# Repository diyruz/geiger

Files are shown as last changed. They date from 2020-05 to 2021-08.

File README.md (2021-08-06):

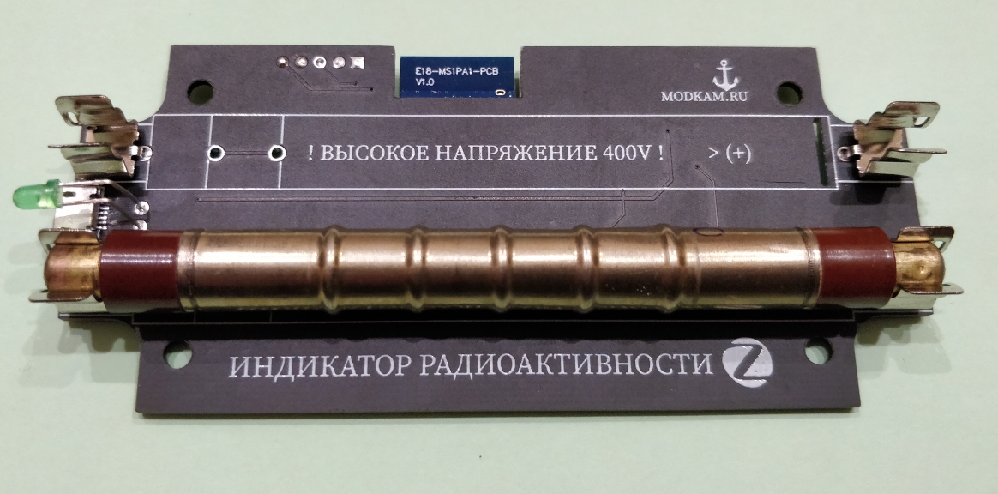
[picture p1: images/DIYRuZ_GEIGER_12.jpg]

We all know what radiation is and its harmful effects on humans. Since this danger is not tangible, in connection with this the idea was born to make an indicator for continuous monitoring of the radiation situation.

The device is not designed to measure the level of radiation in the epicentre of a nuclear explosion, but it allows you to constantly monitor changes in background values. This can be useful in the event of man-made disasters or when you or others bring something with increased background radiation into the house. These can be quite harmless-looking things, nevertheless, they carry a direct threat to life and health.

There are many amateur dosimeter projects, for example, one and two.
All of them are built according to almost the same schemes associated with the features of the Geiger counters used. The principle of operation of Geiger counters is based on the effect of impact ionization of a gaseous medium under the action of radioactive particles in the interelectrode space at a high accelerating voltage. Accordingly, the meter requires a high voltage source.

### How to compile
Follow this article https://zigdevwiki.github.io/Begin/IAR_install/

**ATTENTION! THE DEVICE CONTAINS A HIGH VOLTAGE OF 400 VOLTS**

Since Jager has a Zigbee network at home, the device will be an element of this network.
The circuit does not contain rare elements and is typical for this type of device.

### Diagram
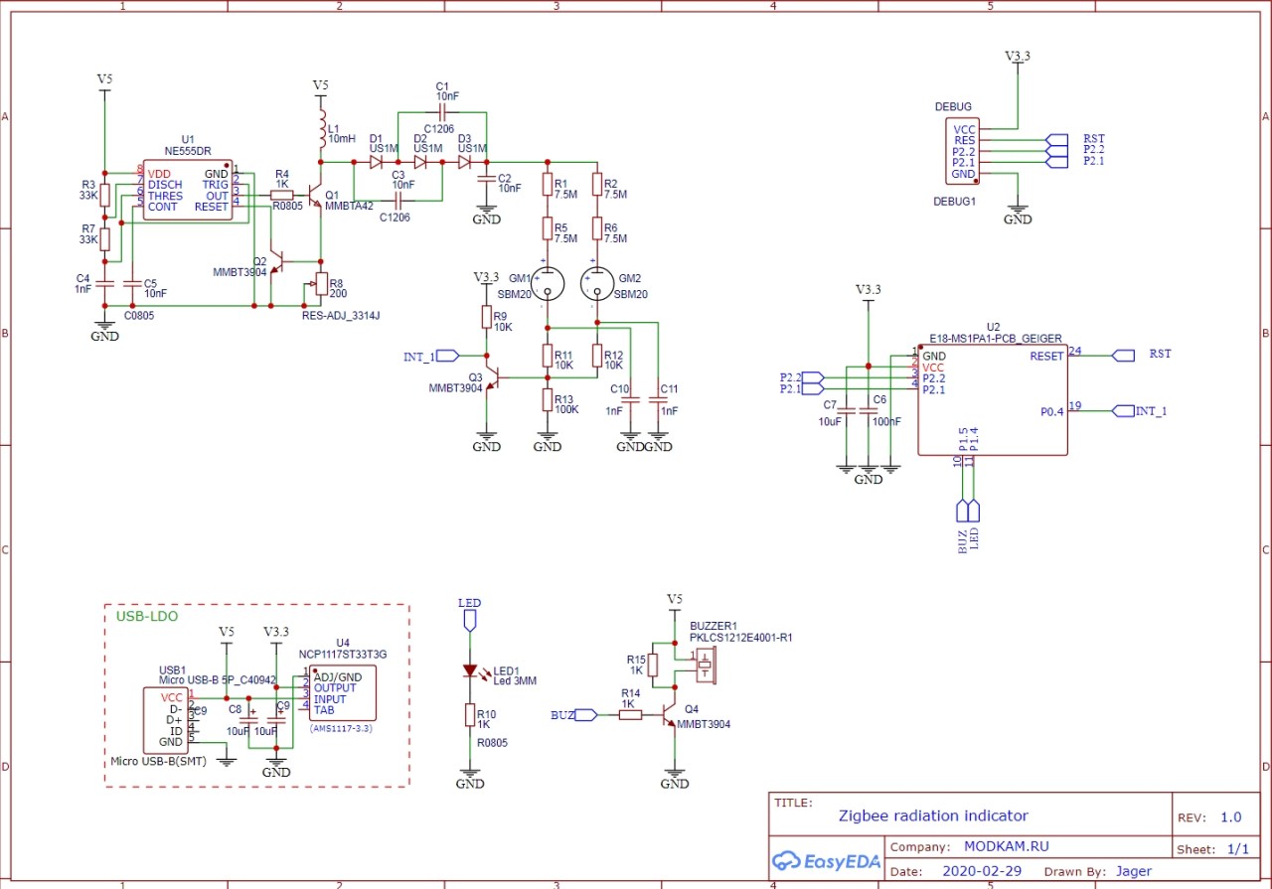
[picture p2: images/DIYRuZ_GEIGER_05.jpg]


The central elements are the SBM-20 Geiger counter and the E18-MS1PA1-PCB Zigbee module. The scheme includes the ability to use either one or two counters to improve the measurement accuracy.
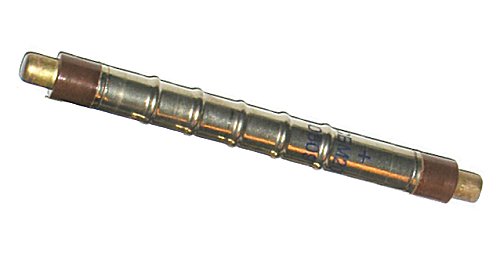
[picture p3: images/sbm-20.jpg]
  

GAINTA 407 case was selected based on the meter size.
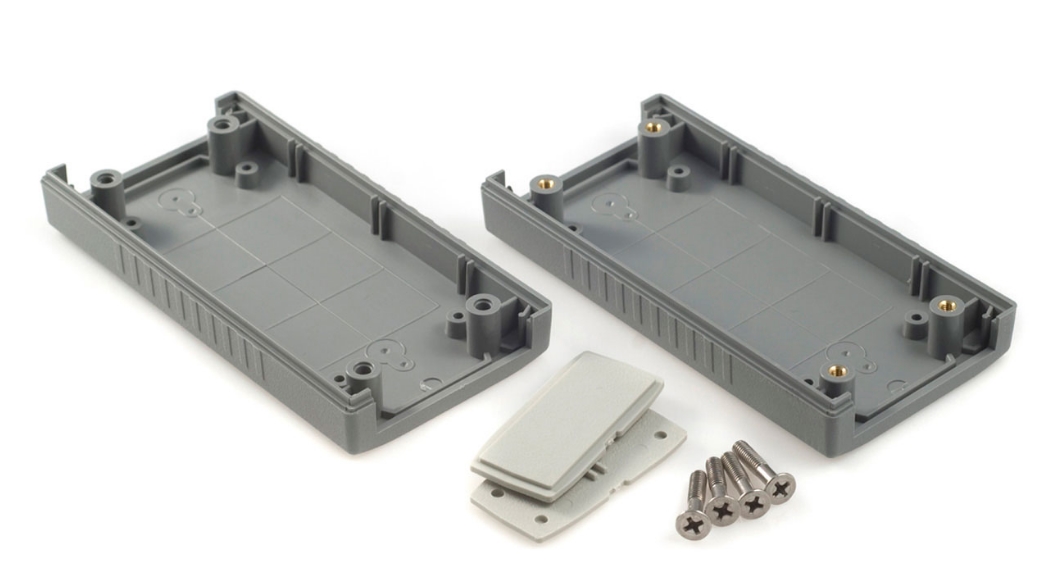
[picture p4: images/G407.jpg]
  

### PCB
The board was designed by EasyEDA
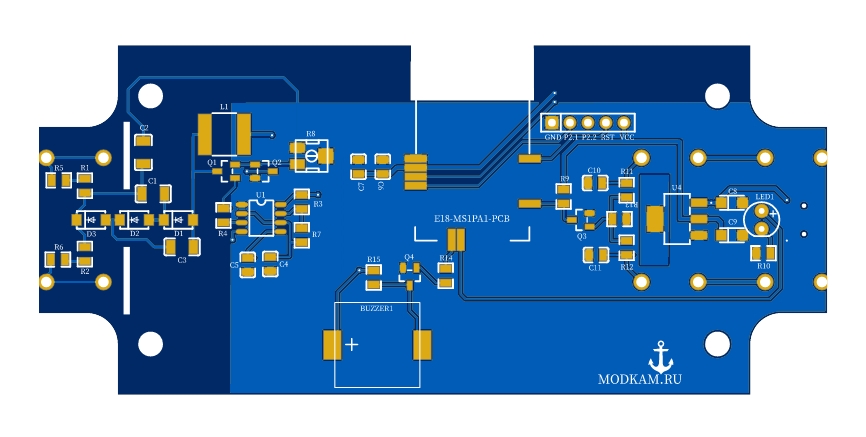
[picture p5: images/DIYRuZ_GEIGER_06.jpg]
  

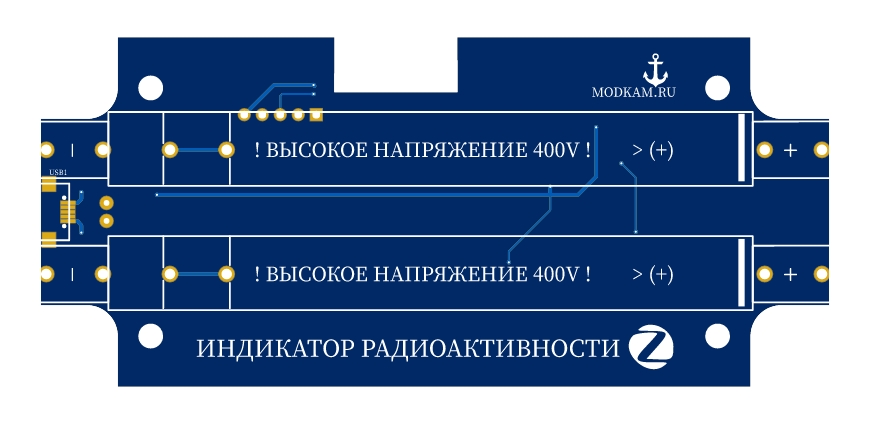
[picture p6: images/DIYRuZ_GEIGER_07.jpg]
  

Production at JLCPCB
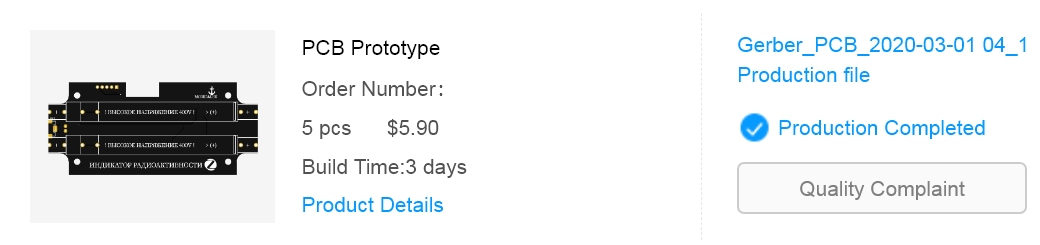
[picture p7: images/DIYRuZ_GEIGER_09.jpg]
  

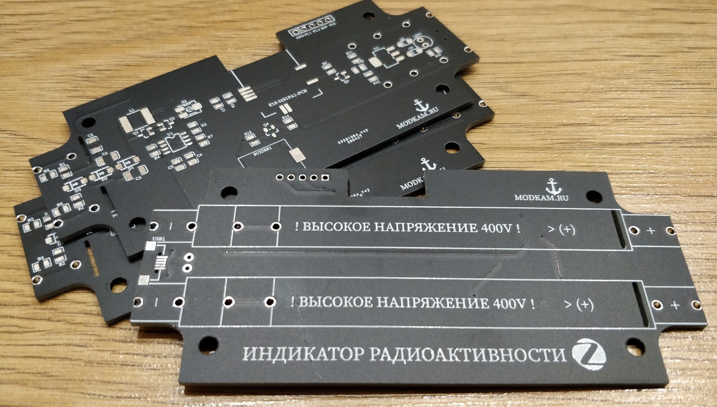
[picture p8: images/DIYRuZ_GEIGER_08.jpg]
  

The general assembly has no peculiarities, the smallest SMD elements are 0805. The capacitors in the voltage multiplier are 600 volts and are 1206 in size. There is a trimmer resistor on the board to set the high voltage level.
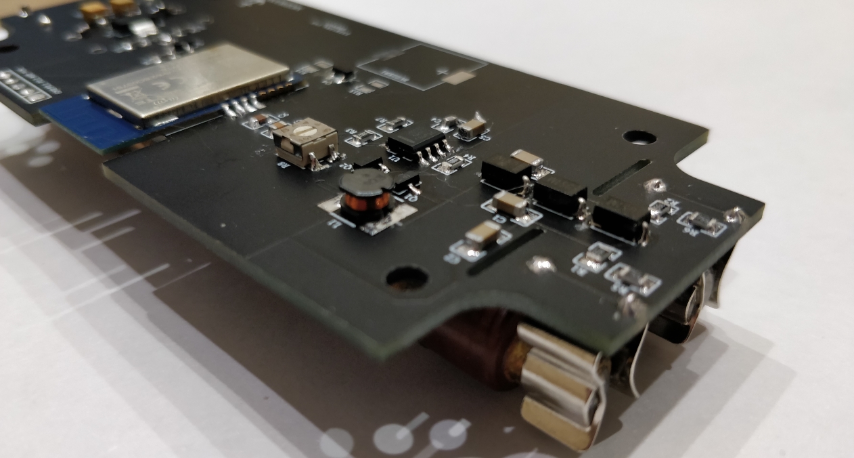
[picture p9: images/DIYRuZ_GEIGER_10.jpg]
  

There is a peculiarity in sealing the meter holders since the width of the case does not allow placing two meters and the micro USB connector at a sufficient distance from each other, the holders must be raised above the board. When soldering, use any 0.8-1.0 mm spacer
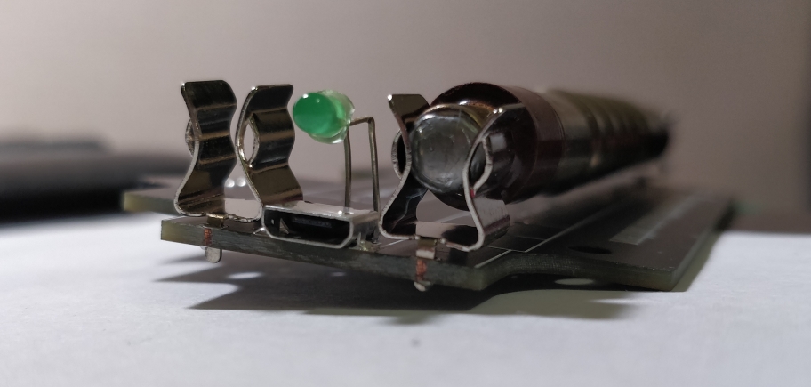
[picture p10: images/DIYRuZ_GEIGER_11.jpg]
  

Physically, you can install counters 90 or 107 mm long.
Such as Soviet SBM-20 and SBM-19 or Chinese J305 and M4011.

To revive the device @anonymass wrote an open-source firmware. The firmware implements support for several counters, displaying the number of registered particles per minute with the conversion of these values to the usual μR / h. An important feature is the ability to set the level at which the alarm is triggered. This condition can be tied to the triggering of a physical siren or light bulb as a means of control and using direct binding on the Zigbee device, which will enable notification even if the Zigbee network is not available.

If the board is correctly assembled, after downloading the firmware, it will be possible to "see" the registered particles immediately  
Zigbee Geiger SBM-20 (https://www.youtube.com/watch?v=Ee7PnegF638)

### Support
Device support is implemented in zigbee2mqtt and SLS Gateway

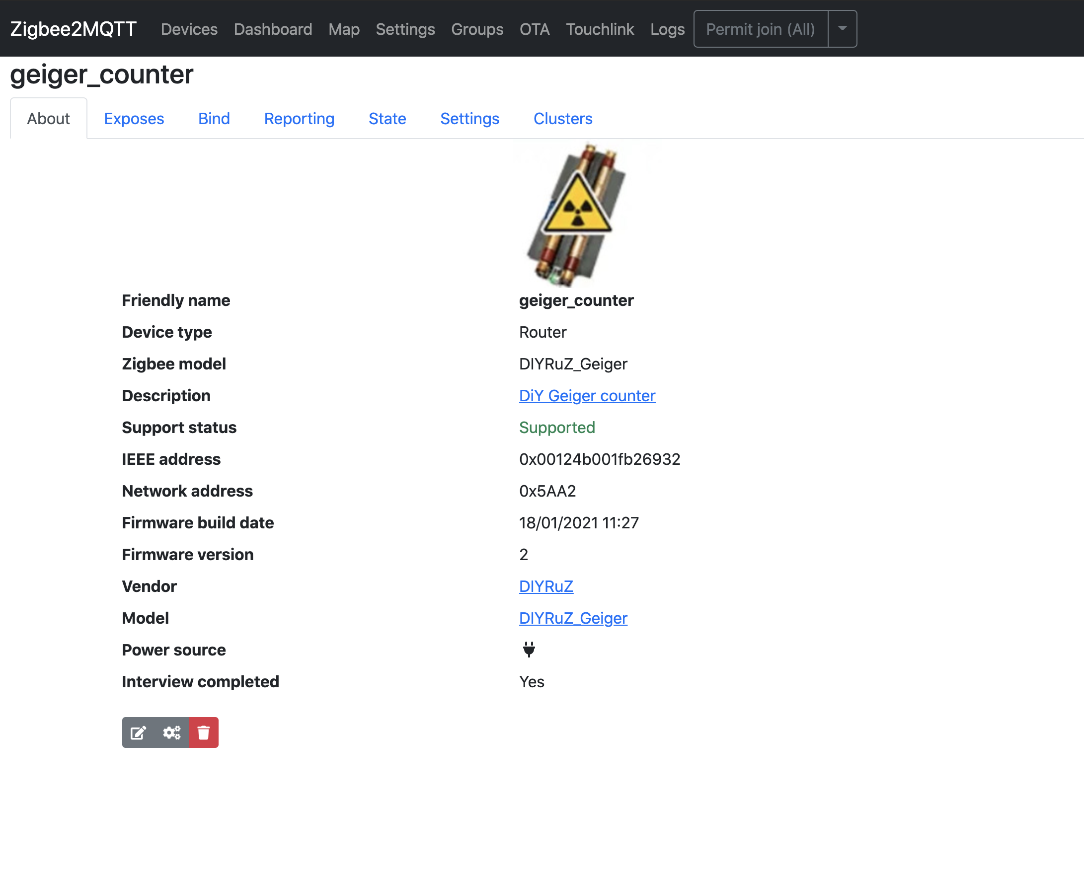
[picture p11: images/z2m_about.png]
   
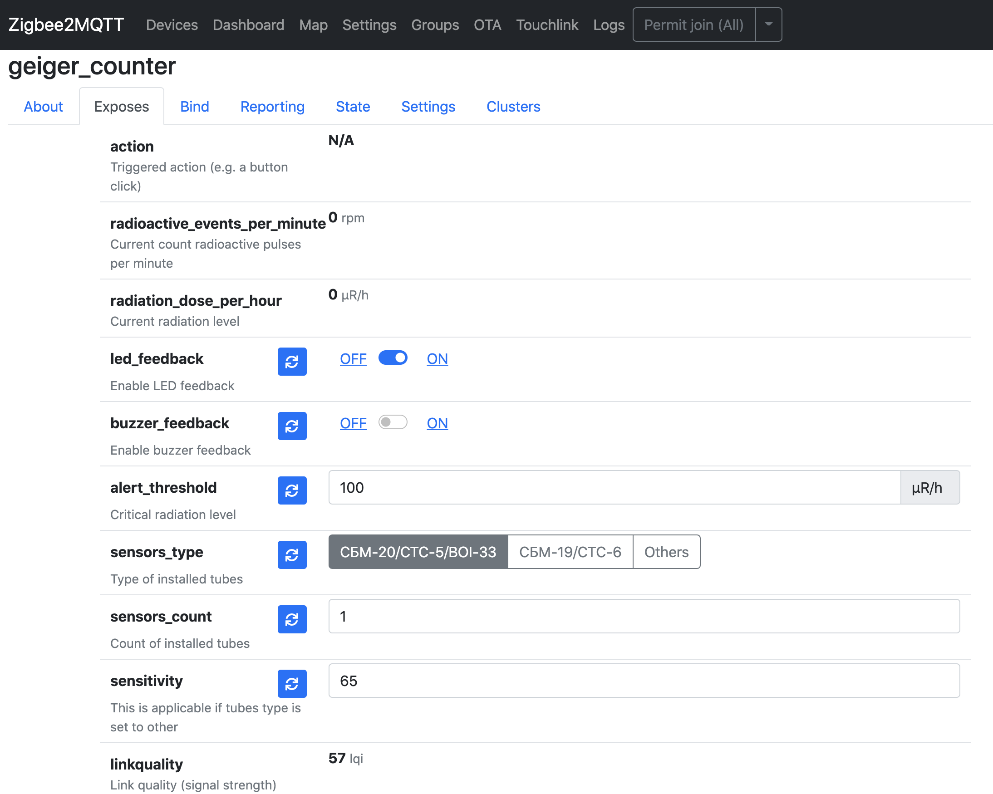
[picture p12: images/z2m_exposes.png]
   

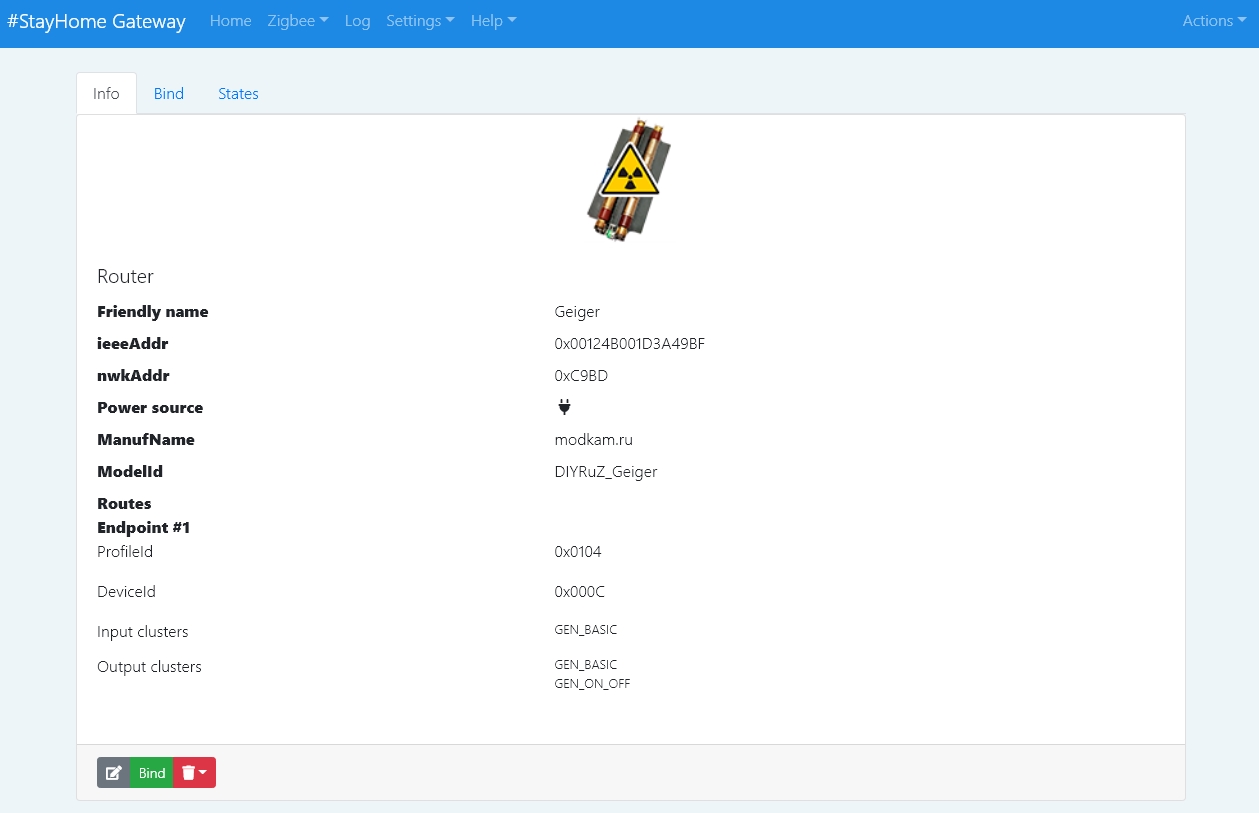
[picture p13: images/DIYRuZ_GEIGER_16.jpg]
  
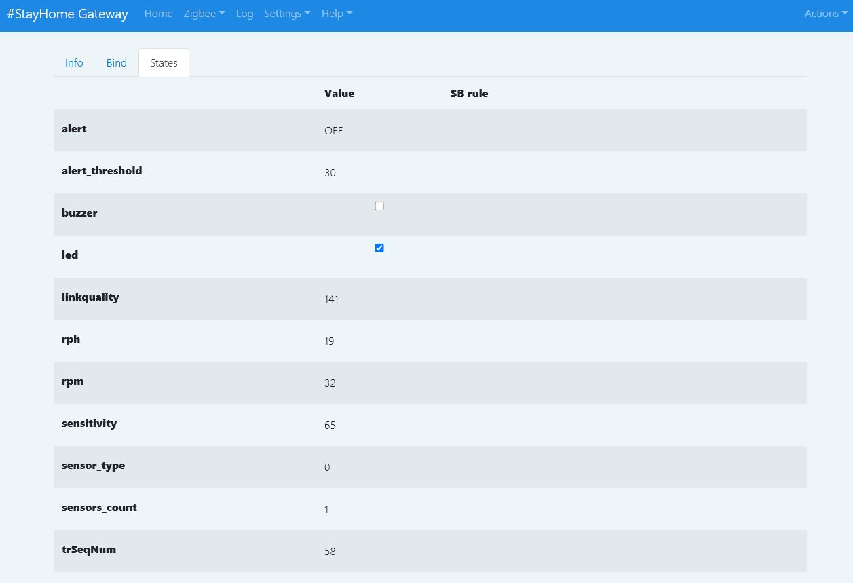
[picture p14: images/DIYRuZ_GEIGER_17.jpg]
  

### Settings
* alert_threshold - set the level in μR / h, when exceeded, the alarm will be triggered

* buzzer - built-in buzzer (not yet supported)

* Led - turn on / off the LED displaying particle registration
* rph - recorded value in μR / h
* pm - recorded value of particles per minute
* sensitivity - counter sensitivity (used if item 3 is selected in sensor_type)
* sensor_type - select the type of meter:
  * SBM-20 / STS-5 / BOI-33
  * SBM-19 / STS-6
  * everything else

* sensors_count - number of installed counters

The device is also a router in the Zigbee network, which allows you to increase its coverage.
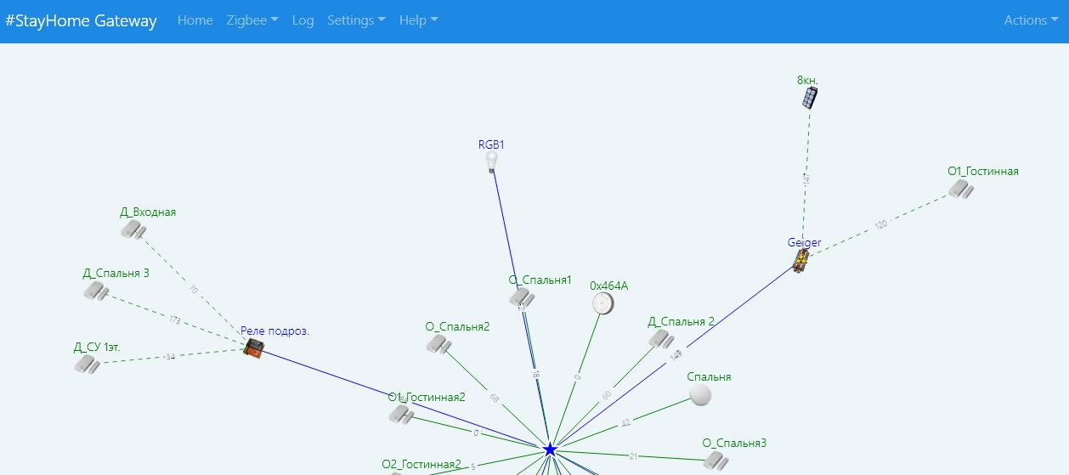
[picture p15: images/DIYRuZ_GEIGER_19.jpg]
  

The final assembly includes installing the board into the case and making an end cap with holes for the LED and micro USB connector. These holes can be made in a standard plug, but Jager drew and printed on a 3D printer
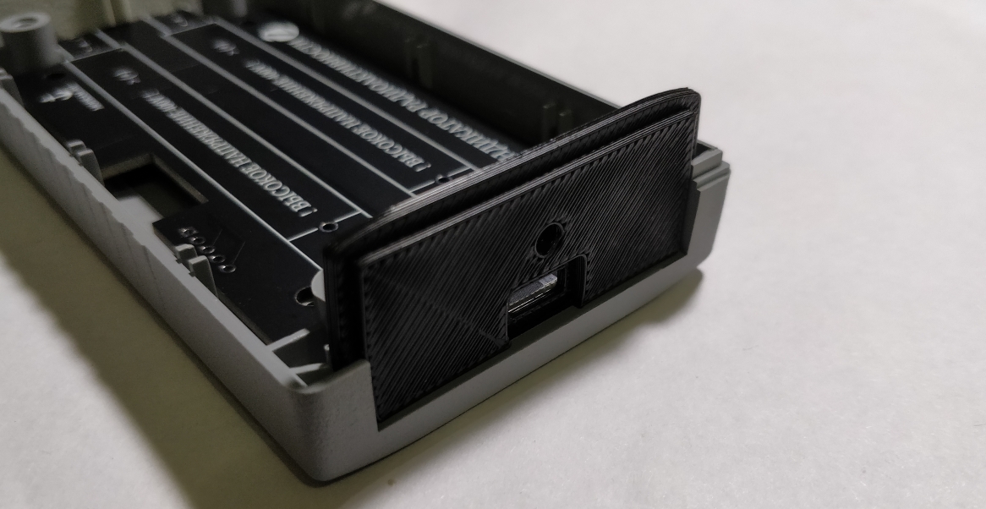
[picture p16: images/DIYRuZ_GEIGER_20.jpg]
  

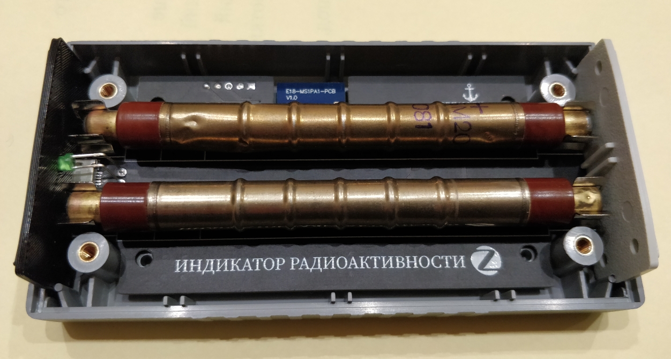
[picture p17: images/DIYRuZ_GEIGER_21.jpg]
  

That's all, the device is ready to go.

In the photos you can see that Jager's counters are damaged, it so happened that Jager got just such. The damage is much more serious and this can be seen in the photo below, but while maintaining the tightness, they do not affect the operation of the meters.
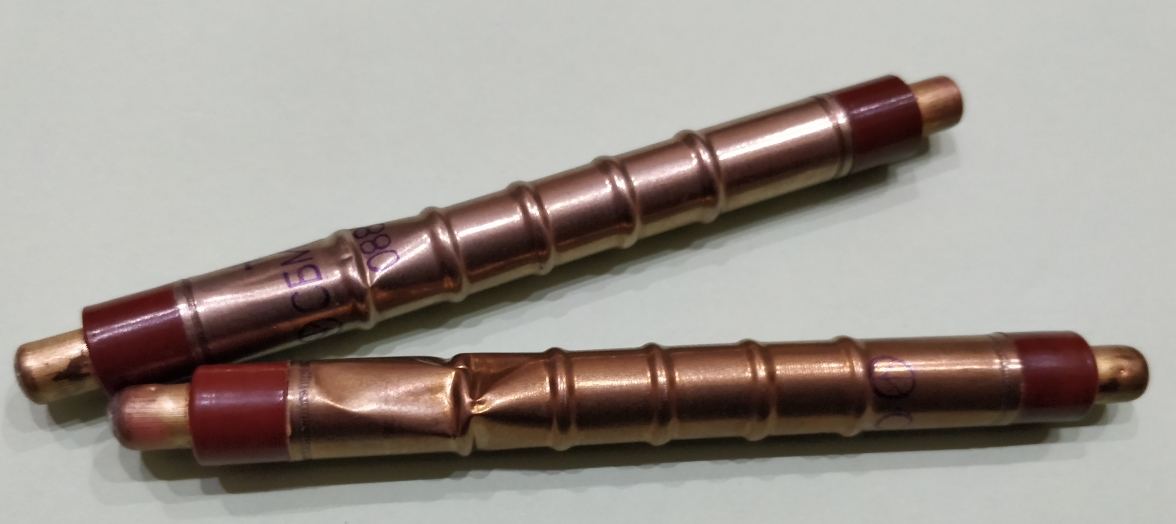
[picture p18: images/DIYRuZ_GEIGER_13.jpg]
  

### How to join
 * Reset to FN rebooting device 5 times with interval less than 10 seconds, LED will start flashing during reset  

### Files to reproduce
* [Gerbers and BOM and STL](https://github.com/diyruz/geiger/tree/master/hardware) by [Jager](https://t.me/Jager_f)  
* [Firmware](https://github.com/diyruz/geiger/releases) by [@anonymass](https://t.me/anonymass)  

[Original post by Jager](https://modkam.ru/?p=1591)

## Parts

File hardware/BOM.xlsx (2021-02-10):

ID | Name | Designator | Footprint | Quantity
1 | SBM20 | GM1,GM2 | SBM20 | 2 | J305 (http://s.click.aliexpress.com/e/_eNhs6r) | M4011 (http://s.click.aliexpress.com/e/_eNupUB)
2 | NE555DR (http://s.click.aliexpress.com/e/_etSvNZ) | U1 | SOIC-8_L5.0-W4.0-P1.27-LS6.0-BL | 1
3 | 10uF | C7 | C0805 | 1
4 | 10nF | C5 | C0805 | 1
5 | US1M | D1,D2,D3 | DO-214AC_L4.3-W2.7-LS5.3-FD | 3
6 | 1K | R4,R10,R14,R15 | R0805 | 4
7 | 33K | R3,R7 | R0805 | 2
8 | 100K | R13 | R0805 | 1
9 | Micro USB-B 5P_C40942 | USB1 | MICRO-USB-12 | 1
10 | PKLCS1212E4001-R1 (http://s.click.aliexpress.com/e/_eKfYZ9) | BUZZER1 | PKLCS1212E4001_BUZ | 1
11 | 100nF | C6 | C0805 | 1
12 | Led 3MM | LED1 | LED_TH_3MM | 1
13 | 10uF | C9,C8 | CAP-SMD_L3.2-W1.6-R-RD | 2
15 | 10mH ** (https://www.chipdip.ru/product/sdr0503-103j) | L1 | IND-SMD_L6.0-W6.0_FNR60XXS | 1 | Ali (http://s.click.aliexpress.com/e/_eswxAR) | Альтернатива (http://s.click.aliexpress.com/e/_eNtSSj)
16 | E18-MS1PA1-PCB (http://s.click.aliexpress.com/e/_eM66Qr) | U2 | E18-MS1PA1-PCB_GEIGER | 1 | Альтернативный магазин (http://s.click.aliexpress.com/e/_eMvMML)
17 | 7.5M | R1,R5,R6,R2 | R0805 | 4
18 | 1nF | C4,C10,C11 | C0805 | 3
19 | MMBTA42 | Q1 | SOT-23-3_L2.9-W1.3-P1.90-LS2.4-BR | 1
20 | 10K | R11,R9,R12 | R0805 | 3
21 | 10nF | C3,C1,C2 | C1206 | 3
22 | 200 | R8 | RES-ADJ_3314J | 1
23 | MMBT3904 | Q2,Q3,Q4 | SOT-23-3_L2.9-W1.3-P1.90-LS2.4-BR | 3
24 | NCP1117ST33T3G (http://s.click.aliexpress.com/e/_eLvrDz) | U4 | SOT-223-3_L6.5-W3.4-P2.30-LS7.0-BR | 1 | AMS1117-3,3 (http://s.click.aliexpress.com/e/_eOdXiR)
 | * В качестве держателей для счетчика Гейгера используются держатели для предохранителей 6мм (расстояние между контактами 8мм). (https://www.chipdip.ru/product/fc-002s)
 | ** По какой то причине на aliexpress отсутствуют индуктивности в исполнении SMD данного номинала
 | точнее они есть, но стоят не дешево.

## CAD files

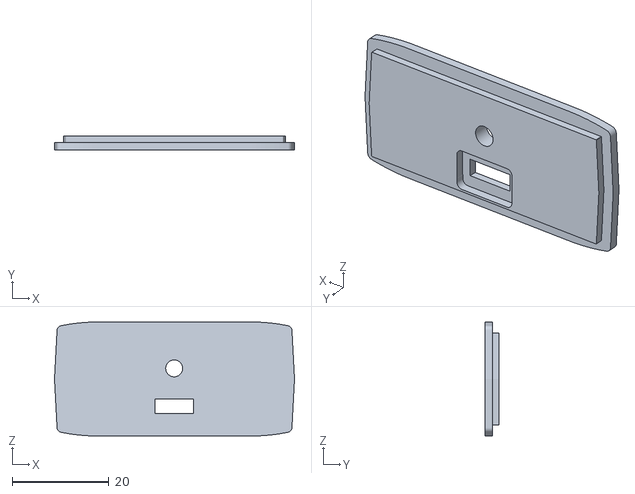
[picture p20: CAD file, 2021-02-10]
hardware/407.STL
49.7 x 2.80 x 23.6

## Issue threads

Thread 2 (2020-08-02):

Проблемка при компиляции с исходников (Z-Stack 3.0.2 и Embedded Workbench 8.1) что я пропустил?

v222008, 2020-08-02:
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

nurikk, 2020-08-03:
По структуре файлов могу сказать что вы точно не последнюю версию исходников скачали, так же рекомендую пользоваться клиентом git для скачивания исходников, а не экспортировать их как zip файл.
Если опыта пользования git нет, то рекомендую использовать [официальный клиент от гитхаба](https://desktop.github.com/) с ним все будет просто и понятно

v222008, 2020-08-27:
> По структуре файлов могу сказать что вы точно не последнюю версию исходников скачали, так же рекомендую пользоваться клиентом git для скачивания исходников, а не экспортировать их как zip файл.
> Если опыта пользования git нет, то рекомендую использовать [официальный клиент от гитхаба](https://desktop.github.com/) с ним все будет просто и понятно

Перекачал через git но всеравно ругается Error[Pe020]: identifier "ZCL_HA_DEVICEID_SIMPLE_SENSOR" is undefined D:\@zigbee\@firmware\Z-Stack 3.0.2\Projects\zstack\HomeAutomation\GenericApp\Source\zcl_app_data.c 113

на строку ZCL_HA_DEVICEID_SIMPLE_SENSOR, //  uint16 AppDeviceId[2];

nurikk, 2020-08-28:
Вы уверены что HomeAutomation\GenericApp относится к индикатору радиоактивности?

v222008, 2020-09-05:
> Вы уверены что HomeAutomation\GenericApp относится к индикатору радиоактивности?

Снес Z-Stack 3.0.2 и переустановил его и проблема ушла сама мобой)

Closed 2020-09-05.

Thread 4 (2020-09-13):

strange values

odenisenko, 2020-09-13:
suddenly values have strange results:

payload_raw: object
radioactive_events_per_minute: 44190
radiation_dose_per_hour: 24988064
linkquality: 86

odenisenko, 2020-09-17:
the sensor is dead. not software issue

Closed 2020-09-17.

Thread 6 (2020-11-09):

Buzzer

frendhomeio, 2020-11-09:
Hello! Could you add buzzer support? (Signal - BUZ. Contact 10 (P1.5) Е18МS)

mapoby, 2021-02-06:
Yes, feature is highly needed.

Calimerorulez, 2021-03-18:
Yes, please add. I thought mine was broken, but just saw it isn't supported jet :)

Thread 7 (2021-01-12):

LED always ON. Radiation values to high and vary from 1000 to 50000

Utyff, 2021-01-12:
Hi,
firmware 1.0.7 have bugs.
LED always ON
Radiation values to high and vary from 1000 to 50000.
You made new firmware from different branch. It made as absolutely new version?

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

Utyff, 2021-01-12:
Something strange about my Geiger. Now the LED is blinking normally and the values have dropped to 600. But there can be no real radioactivity..

Utyff, 2021-01-12:
All works good. Something was wrong with the geiger after the disassemble.

Closed 2021-01-12.

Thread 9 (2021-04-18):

Device resets after some period of time

Actpohomoc, 2021-04-18:
What to do in case device resets after some period of time?
Receives new "nwkAddr" everytime.

2 CTC-5 tubes

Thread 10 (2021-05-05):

Different Zigbee module

BeardedTinker, 2021-05-05:
Hi!

Is it possible to use different Zigbee module.
Instead of E18-MS1PA1-PCB to use E18-MS1PA2-PCB.

I know of differences between two of them  but looks like every module sold now on Ali is PA2 - even if they list it as PA1.

Thank and really great job with this and all similar projects!!!!!!

danieledwardgeorgehitchcock, 2022-05-23:
I watched your youtube video on this back when it was published and I am in the same boat. I have ordered some of the E18-MS1PA2-PCB modules as they look pin-compatible.

Will update this issue if I manage to have any success in fitting and compiling the firmware for the revised board

BeardedTinker, 2022-05-23:
To be honest, I still haven't tried with this module as I managed to find few of the original ones.
In terms of compatibility, I think they are "same" except how you control power of radio part of the module.

Neshco, 2023-11-26:
Can someone of you guys who used PA2 version confirm that everything is fine with it?

Neshco, 2024-08-17:
I can confirm that PA2 module work just fine.

danikdd, 2025-01-23:
> I can confirm that PA2 module work just fine.

Hello, without any modifications or recompiling? Thx for info. Daniel

danikdd, 2025-01-23:
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

Many Thx!

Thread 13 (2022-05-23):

Trim Pot R8 Value

danieledwardgeorgehitchcock, 2022-05-23:
Hi,

On the schematic and BOM, the trim potentiometer is labelled as 200. Is this 200ohm or 200kilohm?

Many thanks!

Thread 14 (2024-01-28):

Alert всегда в состоянии ON

dream700, 2024-01-28:
Для проверки alert_threshold выставил в значение 12, Alert сработал и перешел из состояния OFF в ON, после я alert_threshold поправил на значение 20, но Alert теперь всегда в состоянии ON.
Решил что важен переход через "границу" значения - поставил в 13, уровень поднимался до 15-17, и после вернулся на 11-12 (перенес датчик из ванны в зал 🙂 ) , но Alert по прежнему ON.
Возможно я делаю что то не так, подскажите как правильно работать с alert_threshold и alert

dream700, 2024-01-28:
AREQ_AF_INCOMING_MSG GroupId: 0x0000, ClusterId: 0x0400 MS_ILLUMINANCE_MEASUREMENT, SrcAddr: 0x4F7F, SrcEn: 1, DstEn: 1, WasBr: 0x00, LinkQuality: 76, SecurityUse: 0x00, TimeStamp: 0x0004E37D, TransSeqNum: 0, Len: 15, Data: 18B30A02F0230E00000001F0212F00
86[22:18:51.359] [D]   ZCL FC: 0x18, T: 00, MS: 00, D: 01, DDR: 01, TSN: 179, Cmd: 0x0A REPORT, P: 02F0230E00000001F0212F00
87[22:18:51.376] [D]     AttrId: 0xF002, AttrDataType: 0x23, AttrDataLen: 4, AttrValue: 14
88[22:18:51.383] [D]     AttrId: 0xF001, AttrDataType: 0x21, AttrDataLen: 2, AttrValue: 47
89[22:18:51.390] [V] SetDeviceState nwkAddr: 0x4F7F, radioactive_events_per_minute = UINT16: 47
90[22:18:51.400] [V] SetDeviceState nwkAddr: 0x4F7F, radiation_dose_per_hour = UINT32: 14
91[22:18:51.415] FZ [DIYRuZ_Geiger : 0x00124B002882AD76]: {"alert":"ON","alert_threshold":100,"buzzer_feedback":false,"led_feedback":false,"linkquality":76,"radiation_dose_per_hour":14,"radioactive_events_per_minute":47,"sensitivity":0,"sensors_count":2,"sensors_type":0

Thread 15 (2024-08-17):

Cannot set device to pairing mode in Z2M

Neshco, 2024-08-17:
After months of work without problems, I needed to repair the device because of some mash reorganisation.
I removed the device form the network and tried to set it to the pairing mode by 5 times plug in and out the power, but without success. Tried many times, but it just doesn`t show up in the network.

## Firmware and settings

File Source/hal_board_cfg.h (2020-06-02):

#ifndef HAL_BOARD_CFG_H
#define HAL_BOARD_CFG_H


/* ------------------------------------------------------------------------------------------------
 *                                           Includes
 * ------------------------------------------------------------------------------------------------
 */

#include "hal_mcu.h"
#include "hal_defs.h"
#include "hal_types.h"

/* ------------------------------------------------------------------------------------------------
 *                                       CC2590/CC2591 support
 *
 *                        Define HAL_PA_LNA_CC2590 if CC2530+CC2590EM is used
 *                        Define HAL_PA_LNA if CC2530+CC2591EM is used
 *                        Note that only one of them can be defined
 * ------------------------------------------------------------------------------------------------
 */
#define xHAL_PA_LNA
#define xHAL_PA_LNA_CC2590
#define xHAL_PA_LNA_SE2431L
#define xHAL_PA_LNA_CC2592

/* ------------------------------------------------------------------------------------------------
 *                                          Clock Speed
 * ------------------------------------------------------------------------------------------------
 */

#define HAL_CPU_CLOCK_MHZ     32

/* This flag should be defined if the SoC uses the 32MHz crystal
 * as the main clock source (instead of DCO).
 */
#define HAL_CLOCK_CRYSTAL

/* 32 kHz clock source select in CLKCONCMD */
#if !defined (OSC32K_CRYSTAL_INSTALLED) || (defined (OSC32K_CRYSTAL_INSTALLED) && (OSC32K_CRYSTAL_INSTALLED == TRUE))
  #define OSC_32KHZ  0x00 /* external 32 KHz xosc */
#else
  #define OSC_32KHZ  0x80 /* internal 32 KHz rcosc */
#endif

#define HAL_CLOCK_STABLE()    st( while (CLKCONSTA != (CLKCONCMD_32MHZ | OSC_32KHZ)); )

/* ------------------------------------------------------------------------------------------------
 *                                       LED Configuration
 * ------------------------------------------------------------------------------------------------
 */

#if defined (HAL_BOARD_CHDTECH_DEV)
  #define HAL_NUM_LEDS            3
#elif defined(HAL_BOARD_TARGET)
  #define HAL_NUM_LEDS            1
#else
  #error Unknown Board Indentifier
#endif

#define HAL_LED_BLINK_DELAY()   st( { volatile uint32 i; for (i=0; i<0x5800; i++) { }; } )

#if defined(HAL_BOARD_TARGET)
  #define LED1_BV           BV(4)
  #define LED1_SBIT         P1_4
  #define LED1_DDR          P1DIR
  #define LED1_POLARITY     ACTIVE_HIGH

  #define LED4_BV           BV(4)
  #define LED4_SBIT         P1_4
  #define LED4_DDR          P1DIR
  #define LED4_POLARITY     ACTIVE_HIGH

  #define LED4_BV           BV(4)
  #define LED4_SBIT         P1_4
  #define LED4_DDR          P1DIR
  #define LED4_POLARITY     ACTIVE_HIGH


  #define LED4_BV           BV(4)
  #define LED4_SBIT         P1_4
  #define LED4_DDR          P1DIR
  #define LED4_POLARITY     ACTIVE_HIGH

#elif defined(HAL_BOARD_CHDTECH_DEV)
  #define LED1_BV           BV(0)
  #define LED1_SBIT         P1_0
  #define LED1_DDR          P1DIR
  #define LED1_POLARITY     ACTIVE_LOW

  #define LED2_BV           BV(0)
  #define LED2_SBIT         P1_0
  #define LED2_DDR          P1DIR
  #define LED2_POLARITY     ACTIVE_LOW

  #define LED3_BV           BV(4)
  #define LED3_SBIT         P1_4
  #define LED3_DDR          P1DIR
  #define LED3_POLARITY     ACTIVE_LOW


  #define LED4_BV           BV(4)
  #define LED4_SBIT         P1_4
  #define LED4_DDR          P1DIR
  #define LED4_POLARITY     ACTIVE_LOW
#endif



/* ------------------------------------------------------------------------------------------------
 *                                    Push Button Configuration
 * ------------------------------------------------------------------------------------------------
 */

#define ACTIVE_LOW        !
#define ACTIVE_HIGH       !!    /* double negation forces result to be '1' */

/* S1 */
#define PUSH1_BV          BV(1)
#define PUSH1_SBIT        P0_1




/* ------------------------------------------------------------------------------------------------
 *                         OSAL NV implemented by internal flash pages.
 * ------------------------------------------------------------------------------------------------
 */

// Flash is partitioned into 8 banks of 32 KB or 16 pages.
#define HAL_FLASH_PAGE_PER_BANK    16
// Flash is constructed of 128 pages of 2 KB.
#define HAL_FLASH_PAGE_SIZE        2048
#define HAL_FLASH_WORD_SIZE        4

// CODE banks get mapped into the XDATA range 8000-FFFF.
#define HAL_FLASH_PAGE_MAP         0x8000
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

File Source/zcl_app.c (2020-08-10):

#include "AF.h"
#include "OSAL.h"
#include "OSAL_Clock.h"
#include "OSAL_PwrMgr.h"
#include "ZComDef.h"
#include "ZDApp.h"
#include "ZDObject.h"
#include "math.h"

#include "nwk_util.h"
#include "zcl.h"
#include "zcl_app.h"
#include "zcl_diagnostic.h"
#include "zcl_general.h"
#include "zcl_lighting.h"
#include "zcl_ms.h"

#include "bdb.h"
#include "bdb_interface.h"
#include "bdb_touchlink.h"
#include "bdb_touchlink_target.h"

#include "gp_interface.h"

#include "Debug.h"

#include "onboard.h"

/* HAL */
#include "hal_drivers.h"
#include "hal_key.h"
#include "hal_led.h"
#include "isr_counter.h"

#include "version.h"

#include "calculate_urh.h"

#include "DebugTrace.h"
/*********************************************************************
 * MACROS
 */

/*********************************************************************
 * CONSTANTS
 */

/*********************************************************************
 * TYPEDEFS
 */

/*********************************************************************
 * GLOBAL VARIABLES
 */

extern bool requestNewTrustCenterLinkKey;
byte zclApp_TaskID;

/*********************************************************************
 * GLOBAL FUNCTIONS
 */

/*********************************************************************
 * LOCAL VARIABLES
 */

/*********************************************************************
 * LOCAL FUNCTIONS
 */

static void zclApp_Report(void);
static void zclApp_BasicResetCB(void);
static void zclApp_RestoreAttributesFromNV(void);
static void zclApp_SaveAttributesToNV(void);

static ZStatus_t zclApp_ReadWriteAuthCB(afAddrType_t *srcAddr, zclAttrRec_t *pAttr, uint8 oper);
static void zclApp_RadioactiveEventCB(uint8 portNum);

/*********************************************************************
 * ZCL General Profile Callback table
 */
static zclGeneral_AppCallbacks_t zclApp_CmdCallbacks = {
    zclApp_BasicResetCB, // Basic Cluster Reset command
    NULL,                // Identify Trigger Effect command
    NULL,                // On/Off cluster commands
    NULL,                // On/Off cluster enhanced command Off with Effect
    NULL,                // On/Off cluster enhanced command On with Recall Global Scene
    NULL,                // On/Off cluster enhanced command On with Timed Off
    NULL,                // RSSI Location command
    NULL                 // RSSI Location Response command
};
void zclApp_Init(byte task_id) {
    // debug_str("Hello \r\n");
    DebugInit();
    zclApp_RestoreAttributesFromNV();
    LREP("Sensivity %d led %d buzzer %d \r\n", zclApp_Config.SensorSensivity, zclApp_Config.LedFeedback, zclApp_Config.BuzzerFeedback);
    // this is important to allow connects throught routers
    // to make this work, coordinator should be compiled with this flag #define TP2_LEGACY_ZC
    requestNewTrustCenterLinkKey = FALSE;

    zclApp_TaskID = task_id;

    bdb_RegisterSimpleDescriptor(&zclApp_FirstEP);
    zclGeneral_RegisterCmdCallbacks(zclApp_FirstEP.EndPoint, &zclApp_CmdCallbacks);

    zcl_registerAttrList(zclApp_FirstEP.EndPoint, zclApp_AttrsCount, zclApp_AttrsFirstEP);

    zcl_registerReadWriteCB(zclApp_FirstEP.EndPoint, NULL, zclApp_ReadWriteAuthCB);
    zcl_registerForMsg(zclApp_TaskID);

    ZMacSetTransmitPower(APP_TX_POWER);

    LREP("Build %s \r\n", zclApp_DateCodeNT);

    zclApp_InitCounter();
    zclApp_RegisterCounterCallback(zclApp_RadioactiveEventCB);
    osal_start_reload_timer(zclApp_TaskID, APP_REPORT_EVT, APP_REPORT_DELAY);
}

uint16 zclApp_event_loop(uint8 task_id, uint16 events) {
    LREP("events 0x%x \r\n", events);
    if (events & SYS_EVENT_MSG) {
        afIncomingMSGPacket_t *MSGpkt;
        while ((MSGpkt = (afIncomingMSGPacket_t *)osal_msg_receive(zclApp_TaskID))) {
            LREP("MSGpkt->hdr.event 0x%X clusterId=0x%X\r\n", MSGpkt->hdr.event, MSGpkt->clusterId);
            switch (MSGpkt->hdr.event) {
            case ZCL_INCOMING_MSG:
                if (((zclIncomingMsg_t *)MSGpkt)->attrCmd) {
                    osal_mem_free(((zclIncomingMsg_t *)MSGpkt)->attrCmd);
                }
                break;

            default:
                break;
            }

            // Release the memory
            osal_msg_deallocate((uint8 *)MSGpkt);
        }
        // return unprocessed events
        return (events ^ SYS_EVENT_MSG);
    }
    if (events & APP_REPORT_EVT) {
        LREPMaster("APP_REPORT_EVT\r\n");
        zclApp_Report();
        return (events ^ APP_REPORT_EVT);
    }

    if (events & APP_SAVE_ATTRS_EVT) {
        LREPMaster("APP_SAVE_ATTRS_EVT\r\n");
        zclApp_SaveAttributesToNV();
        return (events ^ APP_SAVE_ATTRS_EVT);
    }
    return 0;
}

bool lastAlertStatus = FALSE;

static void zclApp_Report(void) {
    halIntState_t intState;

    HAL_ENTER_CRITICAL_SECTION(intState);
    zclApp_RadiationEventsPerMinute = zclApp_Port0CounterValue;
    zclApp_Port0CounterValue = 0;
    HAL_EXIT_CRITICAL_SECTION(intState);

    float countsPerSecond = zclApp_RadiationEventsPerMinute / 60.0 / zclApp_Config.SensorsCount;

    switch (zclApp_Config.SensorType) {
    case SBM_19:
        zclApp_RadiationLevelParrotsPerHour = calculate_urh_sbm19(countsPerSecond);
        break;

    case SBM_20:
        zclApp_RadiationLevelParrotsPerHour = calculate_urh_sbm20(countsPerSecond);
        break;

        // TODO: Add other sensors here

    default:
        zclApp_RadiationLevelParrotsPerHour = (uint32)(countsPerSecond * zclApp_Config.SensorSensivity);
        break;
    }
    bool alertStatus = zclApp_RadiationLevelParrotsPerHour > zclApp_Config.AlertTreshold;
    afAddrType_t inderect_DstAddr = {.addrMode = (afAddrMode_t)AddrNotPresent, .endPoint = 0, .addr.shortAddr = 0};
    LREP("AlertTreshold=%ld radiationLevel=%ld\r\n", zclApp_Config.AlertTreshold, zclApp_RadiationLevelParrotsPerHour);
    LREP("alertStatus=%d lastAlertStatus=%d\r\n", alertStatus, lastAlertStatus);

    if (alertStatus != lastAlertStatus) {
        if (alertStatus) {
            zclGeneral_SendOnOff_CmdOn(zclApp_FirstEP.EndPoint, &inderect_DstAddr, FALSE, bdb_getZCLFrameCounter());
        } else {
            zclGeneral_SendOnOff_CmdOff(zclApp_FirstEP.EndPoint, &inderect_DstAddr, FALSE, bdb_getZCLFrameCounter());
        }
        lastAlertStatus = alertStatus;
    }

    LREP("RadiationEventsPerMinute=%d \r\n", zclApp_RadiationEventsPerMinute);
    LREP("s_type=%d s_count=%d radiation(mR/h)=%ld\r\n", zclApp_Config.SensorType, zclApp_Config.SensorsCount, zclApp_RadiationLevelParrotsPerHour);

    bdb_RepChangedAttrValue(zclApp_FirstEP.EndPoint, ILLUMINANCE, ATTRID_RADIATION_EVENTS_PER_MINUTE);
}

static void zclApp_BasicResetCB(void) {
    LREPMaster("BasicResetCB\r\n");
    zclApp_ResetAttributesToDefaultValues();
    zclApp_SaveAttributesToNV();
}
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
